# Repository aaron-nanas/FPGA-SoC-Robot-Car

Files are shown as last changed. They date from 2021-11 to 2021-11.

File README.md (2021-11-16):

# Introduction
This repository includes the Vivado project files of robot car project for my ECE 520 class (System on Chip Design). It makes use of Vivado's IP Integrator feature.

**Note:**
- The C code can be viewed in `Robot_Control_main.c`.
- The files used for 3D printing the structure can be found in the `3D_Models_Print_Files` directory.
- For additional details, check out `ece520_final_project_report.pdf` for a detailed report of this project.

[Click here to watch a short video demonstration.](https://youtu.be/ALcJU5NfLdA)

# Description
Implemented using a Zedboard and written in C, this project involves Vivado's IP Integrator feature and allows interaction with the board's processor. Four DC motors with encoders are used, while a servo controls the attached gripper. For motion control, two Pmod Joysticks ([JSTK2](https://digilent.com/reference/pmod/pmodjstk2/start)) set the directions for the motors.

Moreover, in this design, interrupts are enabled for the push buttons in order to configure the speed of the DC motors.

The structure is mostly 3D printed using the [Original Prusa MINI+](https://shop.prusa3d.com/en/3d-printers/994-original-prusa-mini.html) Printer with PLA filament.

# Block Diagram

Top-Level Hierarchy:

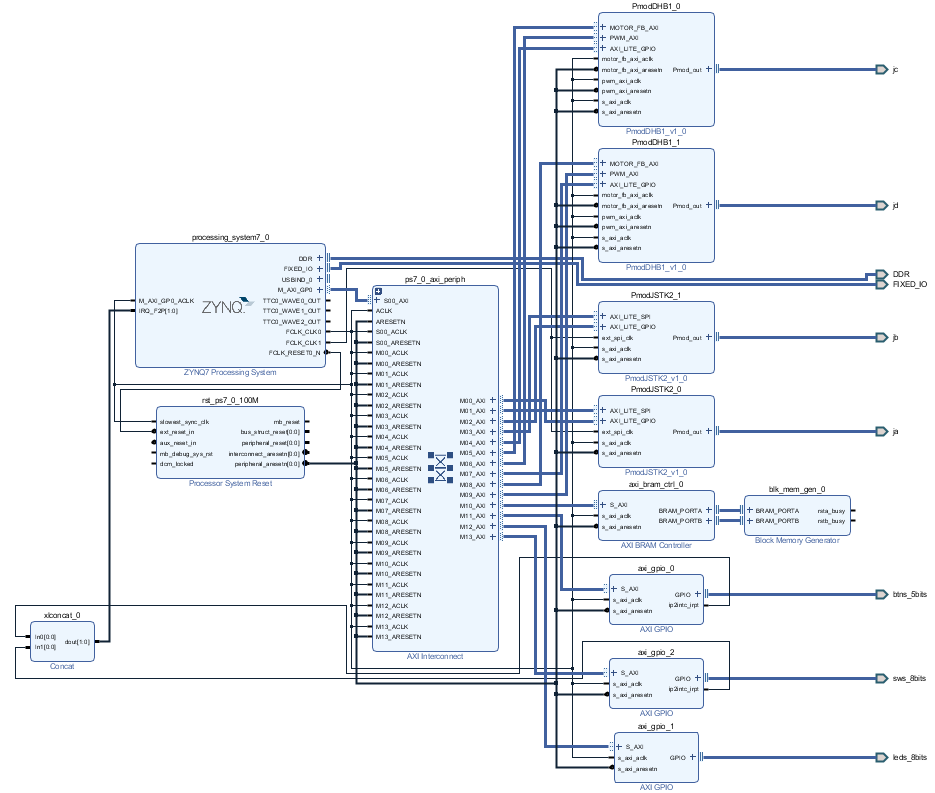
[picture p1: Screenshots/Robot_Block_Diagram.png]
Block Diagram


# Zedbot

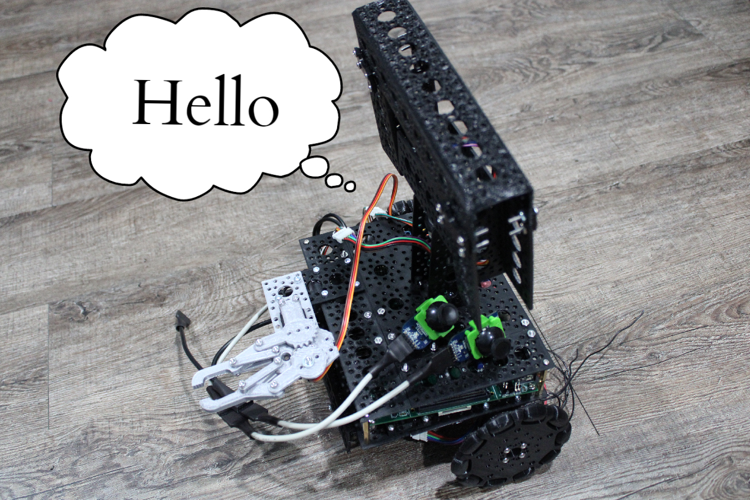
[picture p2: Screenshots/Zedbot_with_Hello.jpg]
Zedbot Image 1


Zedbot Image 2

## Underside of the Zedbot

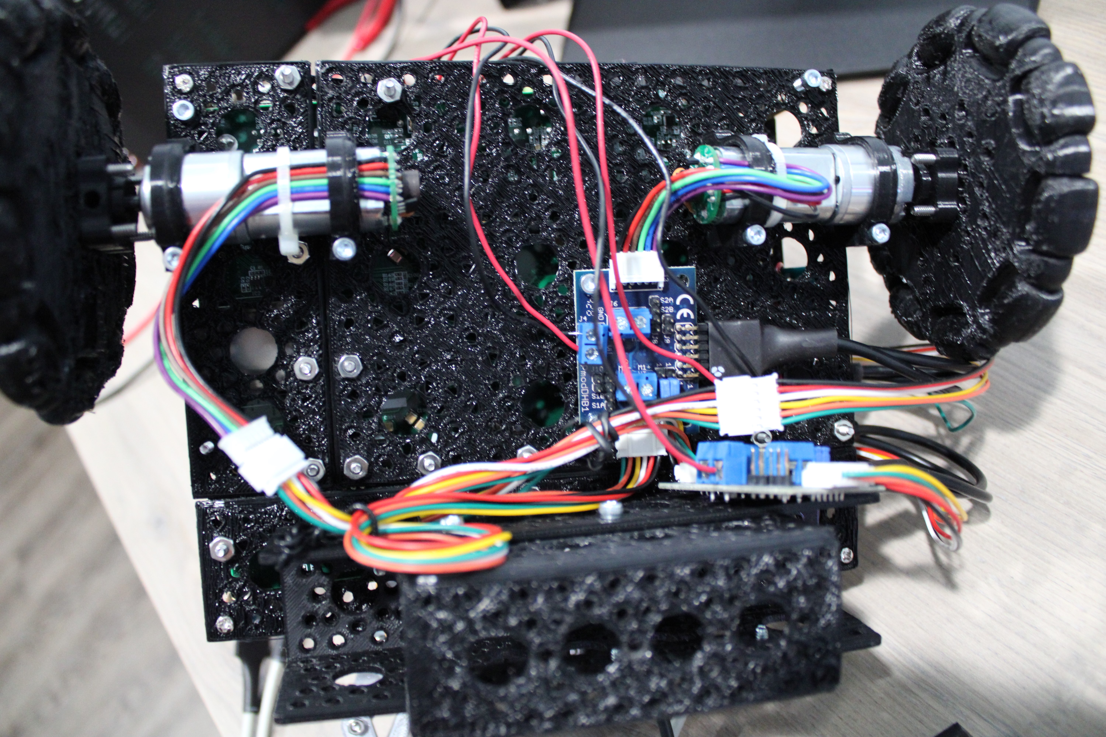
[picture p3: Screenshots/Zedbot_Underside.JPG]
Zedbot Image 3


# Video Demonstration Links

Short Video Demonstration:

[Video Demonstration 1](https://youtu.be/ALcJU5NfLdA)

More about the code:

[Video Demonstration 2](https://youtu.be/0ILeQoVi7fs)

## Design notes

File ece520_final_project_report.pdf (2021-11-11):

# ECE 520

# System on Chip Design

# Final Project Report

# FPGA/SoC Robot Car: Zedbot

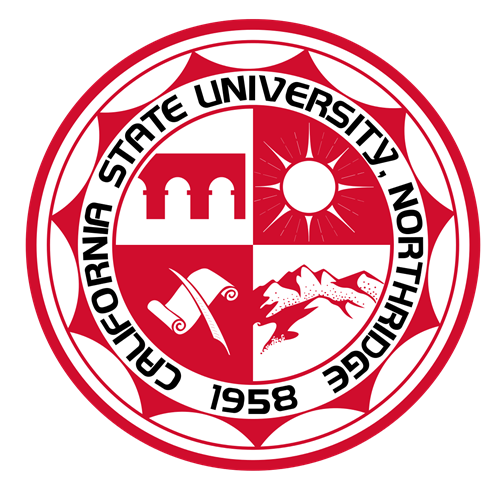
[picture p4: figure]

## Performed By: Aaron Joseph Nanas

## May 17, 2021

## Spring 2021

## Table of Contents

Section | Pg.
Overview | 2
Components Used | 2
Interfacing MIO Pmod | 2
Results | 3-10
References | 11
Appendix | 12-21

## Overview:

This project aims to construct a simple robot car with a pan-and-tilt arm (2-axis) and a gripper using the SoC design flow. The project is implemented using a Zedboard and Digilent Pmods. Vivado 2019.2 with Vitis was used. The design goals are as follows: - Using ServoCity’s open-source 3D models, design a 3D model that can properly house four DC motors with encoders and one servo motor - The design will contain an upper-level platform for a simple 2-DoF (Degrees of Freedom) arm that will eventually hold a camera - The structure must be mostly 3D printed - Two joysticks will control the motion for the DC motors and the servo motor

### The overall structure is mostly 3D printed with Prusament PLA filament, excluding standoffs, nuts, and bolts. The 3D design was created in FreeCAD using ServoCity’s 3D models. Moreover, the gripper model was obtained from an open-source Thingiverse

project.

## Components Used:

The Digilent Pmods used are the following: - Two Pmod JSTK for motion control - Two Pmod DHB1 to drive four DC motors with encoders. These motors control the wheels and the 2-DoF arm - One Pmod CON3 to interface the servo - The Pmod CON3 is connected to the Zedboard’s MIO Pmod (JE) - This Pmod also allows the servo to be separately powered ■ An external power supply (6V) was used to power both the DC motors and the servo motor

## Interfacing MIO Pmod:

### The four Pmod ports (JA, JB, JC, JD) of the Zedboard were already used by the two

Pmod JSTK2 and the two Pmod DHB1. In order to interface the servo motor, the MIO Pmod, specifically the JE1 port, was used to create a simple PWM output. This can easily be done

by writing directly to the pins and using the usleep() function to generate both the frequency required by the servo motor and the duty cycle needed to make a rotation. The driver functions needed for the PS GPIO can be found in the “XGpiops.h” header file. The function that implements a simple PWM output is shown in Figure 2. Moreover, the pins can

be found in the Zedboard’s Hardware User Guide, as shown in Figure 3.

### The rest of the code can be found in the Appendix section of the report, which will

show the functions to drive the car and the push button ISR.

## Results:


### Fig. 1: Zedbot Block Diagram

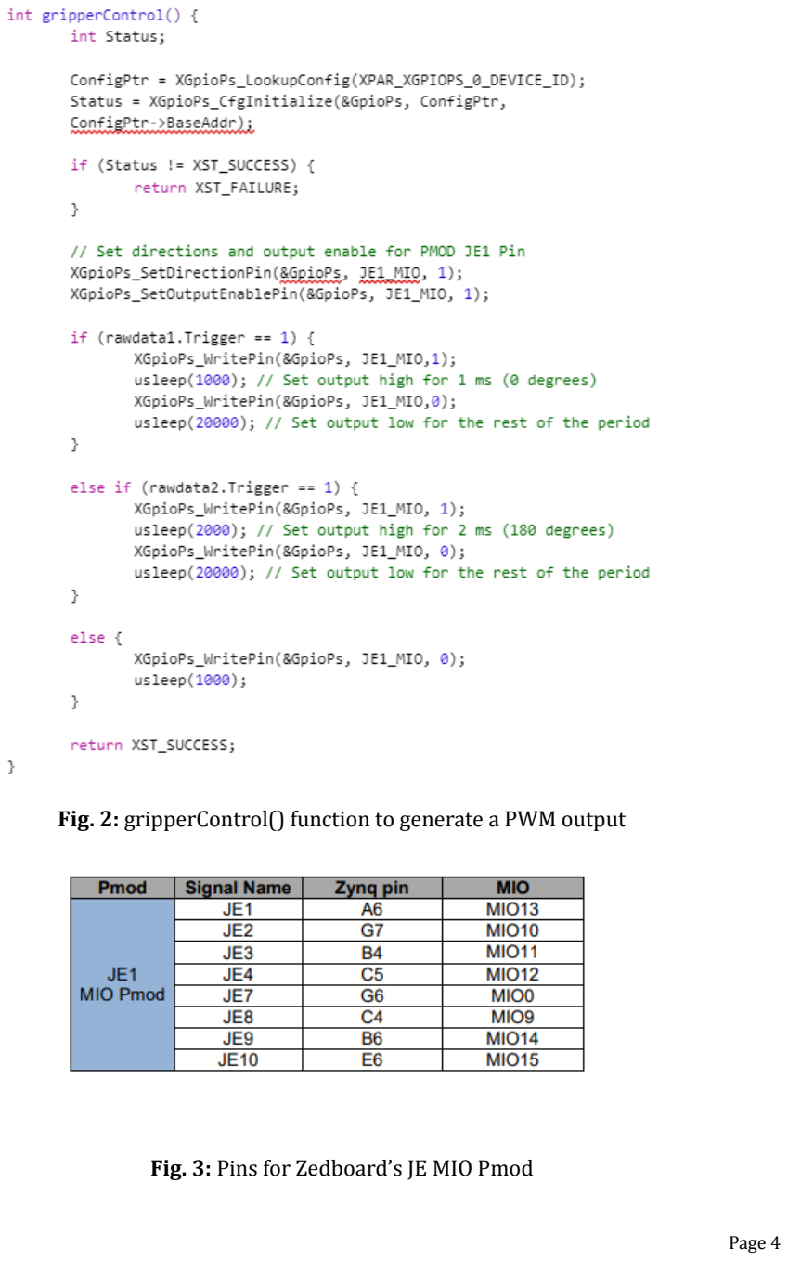
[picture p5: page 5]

### Fig. 2: gripperControl() function to generate a PWM output

### Fig. 3: Pins for Zedboard’s JE MIO Pmod

### Figure 4 presents the 3D two-axis arm model that I designed using ServoCity’s

open-source files.

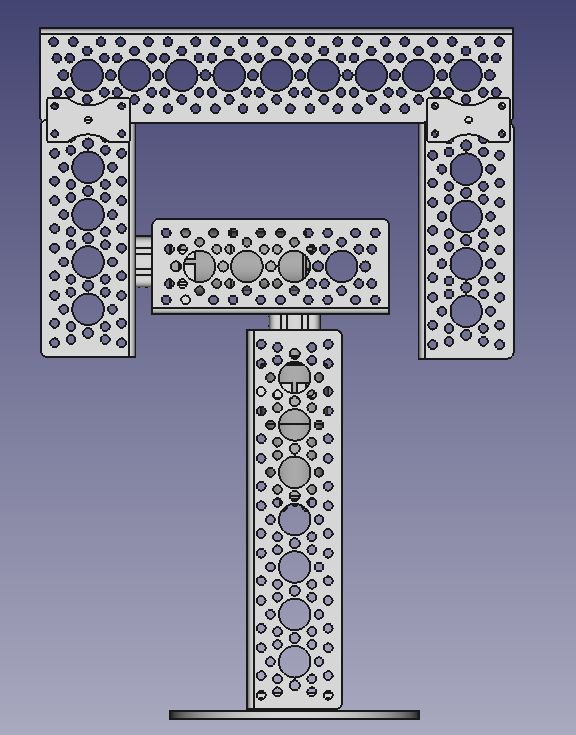
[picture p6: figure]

### Fig. 4: Simple pan-and-tilt arm

Since this is the project’s initial design, the Zedbot can only perform simple tasks: - It can drive forward and backward. It currently does not have steering capability - It can fully rotate the base of the arm, or move it up or down - The idea is that in the future, a camera will be implemented with the Zedboard, providing motion control to a camera and control its positioning - It can grab something close to it with a gripper - Motor speed can be configured with the push button interrupt service routine (ISR)

The following lists the functions used in the main program, with short descriptions for each

function: - void initializePMOD() - This initializes the Pmod JSTK2 and the Pmod DHB1 - void runRobotArm() - This initializes the default speed of the motors - It makes a call to the push button ISR, which can configure the motor speeds - It calls the other functions to drive the robot. It also continuously reads the X and Y values of the two joysticks, and then it initializes the RGB LED located on the joystick - void rotateArm() - This will either tilt the two-axis arm forward or backward, depending on the first joystick’s X and Y values - void rotateBase()

- This will rotate the base of the arm either counter-clockwise or clockwise,

depending on the first joystick’s X and Y values - void driveForward() - This will allow the car to move forward until the specified amount of positive edges is reached (via the feedbackCounter function) depending on the second joystick’s Y values - void driveBackward() - This will allow the car to move backward until the specified amount of positive edges is reached (via the feedbackCounter function) depending on the second joystick’s X values - int gripperControl() - This controls the gripper using the Pmod MIO JE1 port. It uses the usleep() function to generate the frequency and the duty cycle. It directly writes to the PS GPIO using the XGpiops.h header file

- void feedbackCounter_1() and void feedbackCounter_2() - These functions enable the Pmod DHB1 and it will calculate the amount of positive edges when the motor runs. Note that the DC motor has encoders - void BTN_Intr_Handler - The push button interrupt service routine that will configure the motor speeds. Pressing the center button will display the current speeds - int InterruptSystemSetup - Enables the interrupt system for the push buttons - int IntcInitFunction() - This initializes the interrupt controller, and it will enable the GPIO interrupts

### The fully assembled car is shown in the following figure:

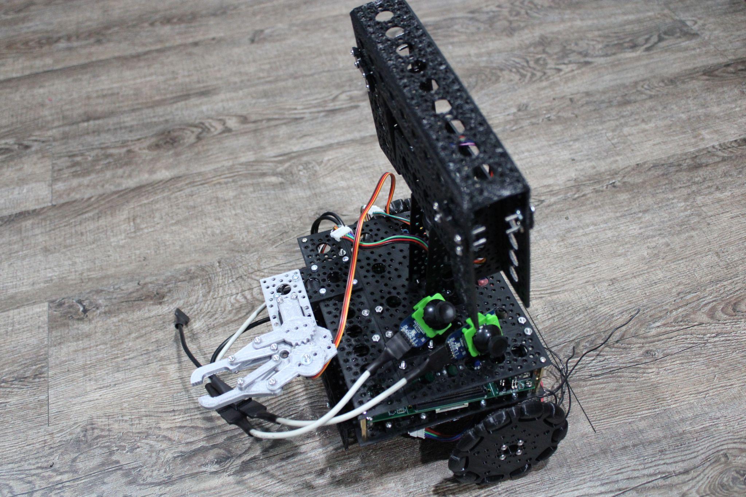
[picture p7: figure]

### Fig. 5: Fully Assembled Car

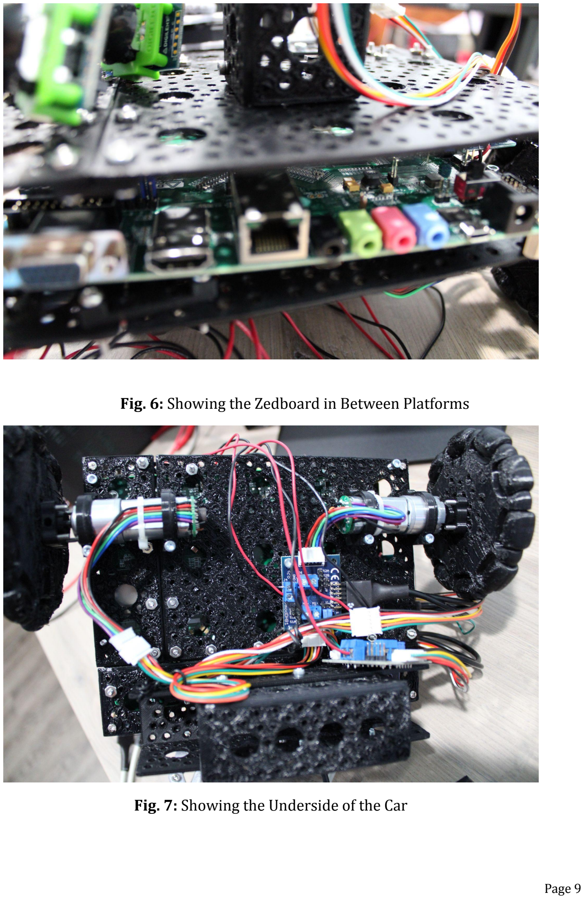
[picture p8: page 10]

### Fig. 6: Showing the Zedboard in Between Platforms

### Fig. 7: Showing the Underside of the Car

### To verify the PWM output, I used an oscilloscope to test if there are any signals coming out of the MIO Pmod of the Zedboard. Figure 8 shows three PWM outputs from the

JE port.

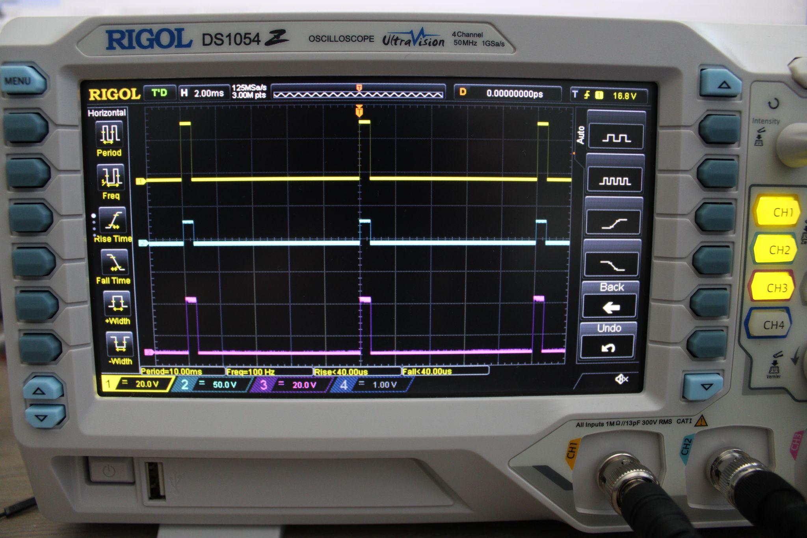
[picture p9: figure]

### Fig. 8: Checking PWM with Oscilloscope

## Video Demonstration Links:

### - Zedbot Short Demonstration: https://youtu.be/0ILeQoVi7fs - Zedbot Second Short Demonstration: https://youtu.be/ALcJU5NfLdA

## References

ServoCity STEP File Library: https://www.servocity.com/step-files/ 3D Model for Arm Claw Gripper: https://www.thingiverse.com/thing:969447 Interfacing Digilent Pmod IPs: https://reference.digilentinc.com/learn/programmable-logic/tutorials/pmod-ips/start Zedboard Reference Manual and Hardware User Guide: https://reference.digilentinc.com/programmable-logic/zedboard/reference-manual

## Appendix:

### Robot Control Main Source C Code:

/* Aaron Joseph Nanas
* ECE 520
* Professor Mirzaei
* Final Project: Robot Car with Arm
*
* Note: Connections are as follows:
* -- First Pmod DHB1: Horizontal and Vertical Axes Motors
* -- Second Pmod DHB1: Wheels
* -- First Pmod JSTK2: Controls the Horizontal and Vertical Axes Motors * -- Second Pmod JSTK2: Controls the wheels
* -- Servo (Pmod MIO JE1): Controls the gripper
*/

// Include Files
#include <stdio.h>

#include <xparameters.h>

#include <xgpiops.h>

#include <xgpio.h>

#include <xscugic.h>

#include <xil_exception.h> #include <xstatus.h>

#include <PmodJSTK2.h>

#include <MotorFeedback.h> #include <PmodDHB1.h>

#include <PWM.h>

#include <sleep.h>

#include <xil_cache.h>

#include <xil_printf.h>

// Base addresses for button ISR
#define INTC_DEVICE_ID | XPAR_PS7_SCUGIC_0_DEVICE_ID

#define BTNS_DEVICE_ID | XPAR_AXI_GPIO_0_DEVICE_ID

#define INTC_GPIO_INTERRUPT_ID

XPAR_FABRIC_AXI_GPIO_0_IP2INTC_IRPT_INTR
#define BTN_INT | XGPIO_IR_CH1_MASK

// Base addresses for first Pmod DHB1
#define GPIO_BASEADDR_1 | XPAR_PMODDHB1_0_AXI_LITE_GPIO_BASEADDR

#define PWM_BASEADDR_1 | XPAR_PMODDHB1_0_PWM_AXI_BASEADDR

#define MOTOR_FB_BASEADDR_1 XPAR_PMODDHB1_0_MOTOR_FB_AXI_BASEADDR

// Base addresses for second Pmod DHB1
#define GPIO_BASEADDR_2 | XPAR_PMODDHB1_1_AXI_LITE_GPIO_BASEADDR

#define PWM_BASEADDR_2 | XPAR_PMODDHB1_1_PWM_AXI_BASEADDR

#define MOTOR_FB_BASEADDR_2 XPAR_PMODDHB1_1_MOTOR_FB_AXI_BASEADDR

#define CLK_FREQ 100000000 // FCLK0 frequency not found in xparameters.h #define CPU_CLOCK_FREQ_HZ (XPAR_PS7_CORTEXA9_0_CPU_CLK_FREQ_HZ)

#define JE1_MIO 13

// Variables for first Pmod DHB1
#define PWM_PER_1 | 2

#define SENSOR_EDGES_PER_REV_1 | 4

#define GEARBOX_RATIO_1 | 53

// Variables for second Pmod DHB1
#define PWM_PER_2 | 2

#define SENSOR_EDGES_PER_REV_2 | 4

#define GEARBOX_RATIO_2 | 53

// Function Prototypes: Motor Control void initializePMOD();
void runRobotArm();
void rotateArm();
void rotateBase();
void driveForward();
void driveBackward();
int gripperControl();
void feedbackCounter_1(int16_t sensor_edges_1); void feedbackCounter_2(int16_t sensor_edges_2);

// Function Prototypes: Push Button ISR
int initializeButtons();
static void BTN_Intr_Handler(void *baseaddr_p);
static int InterruptSystemSetup(XScuGic *XScuGicInstancePtr); static int IntcInitFunction(u16 DeviceId, XGpio *GpioInstancePtr);

// Global Variables and Structs Initialization
PmodJSTK2 joystick1;
PmodJSTK2 joystick2;
PmodDHB1 pmodDHB1_1;
PmodDHB1 pmodDHB1_2;
MotorFeedback motorFeedback1; MotorFeedback motorFeedback2; JSTK2_Position position1;
JSTK2_DataPacket rawdata1; JSTK2_Position position2;

JSTK2_DataPacket rawdata2; XGpioPs GpioPs;
XGpioPs_Config *ConfigPtr; XGpio BTNInst;
XScuGic INTCInst;

static int btn_value;
static int DHB1_1_MOTOR_SPEED; static int DHB1_2_MOTOR_SPEED;

// Calling Functions to Main int main() {

while(1) {
initializePMOD();
runRobotArm();
}

return 0;
}

void initializePMOD() {
DHB1_begin(&pmodDHB1_1, GPIO_BASEADDR_1, PWM_BASEADDR_1, CLK_FREQ, PWM_PER_1); MotorFeedback_init(
&motorFeedback1,
MOTOR_FB_BASEADDR_1,
CLK_FREQ,
SENSOR_EDGES_PER_REV_1,
GEARBOX_RATIO_1
);
DHB1_motorDisable(&pmodDHB1_1);

DHB1_begin(&pmodDHB1_2, GPIO_BASEADDR_2, PWM_BASEADDR_2, CLK_FREQ, PWM_PER_2); MotorFeedback_init(
&motorFeedback2,
MOTOR_FB_BASEADDR_2,
CLK_FREQ,
SENSOR_EDGES_PER_REV_2,
GEARBOX_RATIO_2
);
DHB1_motorDisable(&pmodDHB1_2);

// Initialize the Pmod Joystick device JSTK2_begin(
&joystick1,
XPAR_PMODJSTK2_0_AXI_LITE_SPI_BASEADDR, XPAR_PMODJSTK2_0_AXI_LITE_GPIO_BASEADDR

);

// Set inversion register to invert only the Y axis JSTK2_setInversion(&joystick1, 0, 1);

// Initialize Joystick 2 device
JSTK2_begin(
&joystick2,
XPAR_PMODJSTK2_1_AXI_LITE_SPI_BASEADDR, XPAR_PMODJSTK2_1_AXI_LITE_GPIO_BASEADDR
);

// Set inversion register to invert only the Y axis JSTK2_setInversion(&joystick2, 0, 1);
}

int initializeButtons() {
int status;

status = XGpio_Initialize(&BTNInst, BTNS_DEVICE_ID);

if(status != XST_SUCCESS) return XST_FAILURE;

XGpio_SetDataDirection(&BTNInst, 1, 0xFF);

// Initialize interrupt controller
status = IntcInitFunction(INTC_DEVICE_ID, &BTNInst); if(status != XST_SUCCESS) return XST_FAILURE;

return 0;
}

void runRobotArm() {
DHB1_1_MOTOR_SPEED = 50;
DHB1_2_MOTOR_SPEED = 90;
DHB1_setMotorSpeeds(&pmodDHB1_1, DHB1_1_MOTOR_SPEED, DHB1_1_MOTOR_SPEED); DHB1_setMotorSpeeds(&pmodDHB1_2, DHB1_2_MOTOR_SPEED, DHB1_2_MOTOR_SPEED);

initializeButtons();
MotorFeedback_clearPosCounter(&motorFeedback1); MotorFeedback_clearPosCounter(&motorFeedback2); // Get X and Y values of the Joystick position1 = JSTK2_getPosition(&joystick1); position2 = JSTK2_getPosition(&joystick2);
// Get Joystick button data
rawdata1 = JSTK2_getDataPacket(&joystick1); rawdata2 = JSTK2_getDataPacket(&joystick2);

//xil_printf(
// | "%s%s%s%s\r\n",
// | (rawdata1.Jstk != 0) ? "\tJoystick 1 pressed" : "",
// | (rawdata1.Trigger != 0) ? "\tTrigger 1 pressed" : "",
// | (rawdata2.Jstk != 0) ? "\tJoystick 2 pressed" : "",
// | (rawdata2.Trigger != 0) ? "\tTrigger 2 pressed" : ""
// | );
//usleep(50000);

// Initialize the Joystick RGB LEDs
if ((rawdata1.Jstk != 0 || rawdata1.Trigger != 0) && (rawdata2.Jstk == 0 || rawdata2.Trigger == 0)) {
JSTK2_setLedRGB(&joystick1, 0, 255, 0);
}
else if ((rawdata2.Jstk != 0 || rawdata2.Trigger != 0) && (rawdata1.Jstk == 0 || rawdata1.Trigger == 0)) {
| JSTK2_setLedRGB(&joystick2, 0, 255, 0);
}
else {
| JSTK2_setLedRGB(&joystick1, position1.XData, 0, position1.YData);
| JSTK2_setLedRGB(&joystick2, position2.XData, 0, position2.YData);
}
driveForward();
driveBackward();
rotateArm();
rotateBase();
gripperControl();
}

void rotateArm() {
DHB1_setMotorSpeeds(&pmodDHB1_1, 0, 50);
if ((position1.XData == 128) && (position1.YData >= 150)) { // Checks for when the first joystick's direction is up
| DHB1_motorDisable(&pmodDHB1_1);
| usleep(6);
| DHB1_setDirs(&pmodDHB1_1, 0, 0); // Move the arm forward
| feedbackCounter_1(5);
}

else if ((position1.XData == 128) && (position1.YData <= 100)) { // Checks for when the first joystick's direction is down
| DHB1_motorDisable(&pmodDHB1_1);
| usleep(6);
| DHB1_setDirs(&pmodDHB1_1, 1, 1); // Move the arm backward
| feedbackCounter_1(5);

}
}

void rotateBase() {
DHB1_setMotorSpeeds(&pmodDHB1_1, 50, 0);
if ((position1.XData <= 100) && (position1.YData == 128)) { // Checks for when the first joystick's direction is left
DHB1_motorDisable(&pmodDHB1_1);
usleep(6);
DHB1_setDirs(&pmodDHB1_1, 1, 1); // Rotate the base counter-clockwise feedbackCounter_1(5);
}

else if ((position1.XData >= 150) && (position1.YData == 128)) { // Checks for when the first joystick's direction is right DHB1_motorDisable(&pmodDHB1_1);
usleep(6);
DHB1_setDirs(&pmodDHB1_1, 0, 0); // Rotate the base clockwise feedbackCounter_1(5);
}
}

void driveForward() {
if ((position2.XData == 128) && (position2.YData >= 129)) { // Checks for when the second joystick's direction is up DHB1_motorDisable(&pmodDHB1_2); // Disable the PWM before the motors change direction
usleep(6); | // Adding a short delay to prevent
short circuit
DHB1_setDirs(&pmodDHB1_2, 1, 1); // Set direction forward feedbackCounter_2(240); // Motor runs until the specified amount of positive edges is reached
}
}

void driveBackward() {
if ((position2.XData == 128) && (position2.YData <= 127)) { // Checks for when the second joystick's direction is down DHB1_motorDisable(&pmodDHB1_2); // Disable the PWM before the motors change direction
usleep(6); | // Adding a short delay to prevent
short circuit
DHB1_setDirs(&pmodDHB1_2, 0, 0); // Set direction backward feedbackCounter_2(240); // Motor runs until the specified amount of positive edges is reached
}
}

// Function to drive the servo using the Pmod MIO JE1 port
// Uses usleep function to generate the frequency and duty cycle int gripperControl() {
int Status;

ConfigPtr = XGpioPs_LookupConfig(XPAR_XGPIOPS_0_DEVICE_ID); Status = XGpioPs_CfgInitialize(&GpioPs, ConfigPtr, ConfigPtr->BaseAddr);

if (Status != XST_SUCCESS) {
return XST_FAILURE;
}

// Set directions and output enable for PMOD JE1 Pin XGpioPs_SetDirectionPin(&GpioPs, JE1_MIO, 1); XGpioPs_SetOutputEnablePin(&GpioPs, JE1_MIO, 1);

if (rawdata1.Trigger == 1) {
XGpioPs_WritePin(&GpioPs, JE1_MIO,1);
usleep(1000); // Set output high for 1 ms (0 degrees) XGpioPs_WritePin(&GpioPs, JE1_MIO,0);
usleep(20000); // Set output low for the rest of the period }

else if (rawdata2.Trigger == 1) {
XGpioPs_WritePin(&GpioPs, JE1_MIO, 1);
usleep(2000); // Set output high for 2 ms (180 degrees) XGpioPs_WritePin(&GpioPs, JE1_MIO, 0);
usleep(20000); // Set output low for the rest of the period }

else {
XGpioPs_WritePin(&GpioPs, JE1_MIO, 0); usleep(1000);
}

return XST_SUCCESS;
}

void feedbackCounter_1(int16_t sensor_edges_1) { DHB1_motorEnable(&pmodDHB1_1);
int16_t dist_1 = MotorFeedback_getDistanceTraveled(&motorFeedback1); while (dist_1 < sensor_edges_1) {
dist_1 = MotorFeedback_getDistanceTraveled(&motorFeedback1);
}
MotorFeedback_clearPosCounter(&motorFeedback1);

DHB1_motorDisable(&pmodDHB1_1);
}

void feedbackCounter_2(int16_t sensor_edges_2) { DHB1_motorEnable(&pmodDHB1_2);
int16_t dist_2 = MotorFeedback_getDistanceTraveled(&motorFeedback2); while (dist_2 < sensor_edges_2) {
dist_2 = MotorFeedback_getDistanceTraveled(&motorFeedback2);
}
MotorFeedback_clearPosCounter(&motorFeedback2); DHB1_motorDisable(&pmodDHB1_2);
}

void BTN_Intr_Handler(void *InstancePtr)
{
// Disable GPIO interrupts XGpio_InterruptDisable(&BTNInst, BTN_INT);
// Ignore additional button presses
if ((XGpio_InterruptGetStatus(&BTNInst) & BTN_INT) != BTN_INT) {
return;
}
btn_value = XGpio_DiscreteRead(&BTNInst, 1);

if (btn_value == 1) {
xil_printf("\nCurrent Motor Speeds: \n" "DHB1_1 Motors: %d\n"
"DHB1_2 Motors: %d\n",DHB1_1_MOTOR_SPEED, DHB1_2_MOTOR_SPEED );
}

else if (btn_value == 4) {
xil_printf("\nLeft button (BTNL) was pressed. Decreasing DHB1_1 Motor Speed.\n");
DHB1_1_MOTOR_SPEED = DHB1_1_MOTOR_SPEED - 5;
xil_printf("\nCurrent Speed of DHB1_1 Motors (Arm/Base): %d\n", DHB1_1_MOTOR_SPEED);
}

else if (btn_value == 8) {
xil_printf("\nRight button (BTNR) was pressed. Increasing DHB1_1 Motor Speed.\n");
DHB1_1_MOTOR_SPEED = DHB1_1_MOTOR_SPEED + 5;
xil_printf("\nCurrent Speed of DHB1_1 Motors (Arm/Base): %d\n", DHB1_1_MOTOR_SPEED);
}

else if (btn_value == 16) {
xil_printf("\nUp button (BTNU) was pressed. Increasing DHB1_2 Motor Speed.\n");
DHB1_2_MOTOR_SPEED = DHB1_2_MOTOR_SPEED + 5;
xil_printf("\nCurrent Speed of DHB1_2 Motors (Wheels): %d\n", DHB1_2_MOTOR_SPEED);
}

else if (btn_value == 2) {
xil_printf("\nDown button (BTND) was pressed. Decreasing DHB1_2 Motor Speed.\n");
DHB1_2_MOTOR_SPEED = DHB1_2_MOTOR_SPEED - 5;
xil_printf("\nCurrent Speed of DHB1_2 Motors (Wheels): %d\n", DHB1_2_MOTOR_SPEED);
}

(void)XGpio_InterruptClear(&BTNInst, BTN_INT); // Enable GPIO interrupts
XGpio_InterruptEnable(&BTNInst, BTN_INT);
}

int InterruptSystemSetup(XScuGic *XScuGicInstancePtr) {
// Enable interrupt
XGpio_InterruptEnable(&BTNInst, BTN_INT); XGpio_InterruptGlobalEnable(&BTNInst); Xil_ExceptionRegisterHandler(XIL_EXCEPTION_ID_INT,

(Xil_ExceptionHandler)XScuGic_InterruptHandler, XScuGicInstancePtr);
Xil_ExceptionEnable();
return XST_SUCCESS;
}
int IntcInitFunction(u16 DeviceId, XGpio *GpioInstancePtr) {
XScuGic_Config *IntcConfig;
int status;

// Interrupt controller initialization
IntcConfig = XScuGic_LookupConfig(DeviceId);
status = XScuGic_CfgInitialize(&INTCInst, IntcConfig, IntcConfig->CpuBaseAddress);

if(status != XST_SUCCESS)
return XST_FAILURE;

// Call to interrupt setup status = InterruptSystemSetup(&INTCInst); if(status != XST_SUCCESS)
return XST_FAILURE;

// Connect GPIO interrupt to handler status = XScuGic_Connect(&INTCInst, INTC_GPIO_INTERRUPT_ID,
(Xil_ExceptionHandler)BTN_Intr_Handler, (void *)GpioInstancePtr);

if(status != XST_SUCCESS)
return XST_FAILURE;

// Enable GPIO interrupts interrupt XGpio_InterruptEnable(GpioInstancePtr, 1); XGpio_InterruptGlobalEnable(GpioInstancePtr);

// Enable GPIO and timer interrupts in the controller XScuGic_Enable(&INTCInst, INTC_GPIO_INTERRUPT_ID);

return XST_SUCCESS;
}

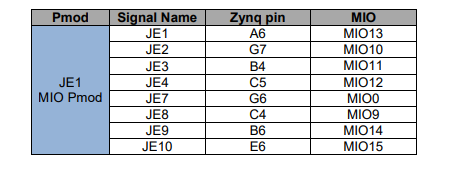
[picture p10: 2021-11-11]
Screenshots/zedboard_mio.png

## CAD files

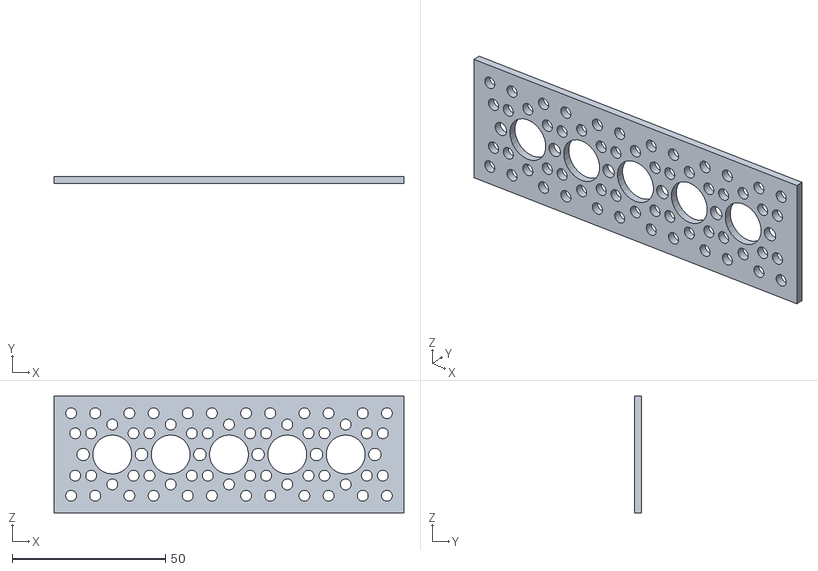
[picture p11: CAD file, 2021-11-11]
3D_Models_Print_Files/RobotArm_V3_STL_Files/1-5in_4-50in_PatternPlate.stl
114.3 x 2.29 x 38.1

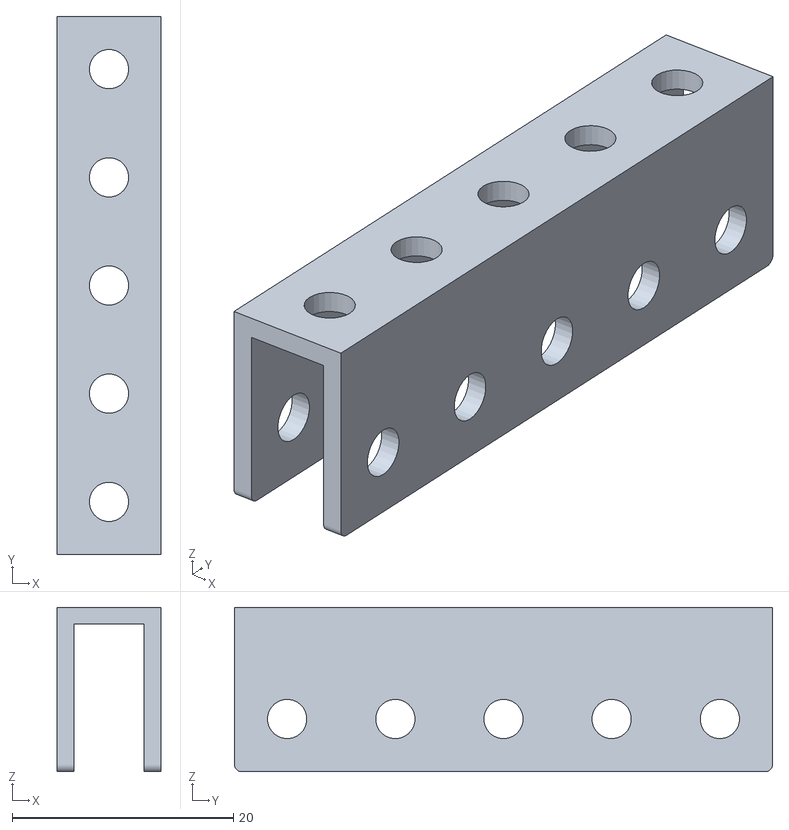
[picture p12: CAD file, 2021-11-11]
3D_Models_Print_Files/RobotArm_V3_STL_Files/1-54in_U-Beam.stl
9.40 x 48.6 x 14.9

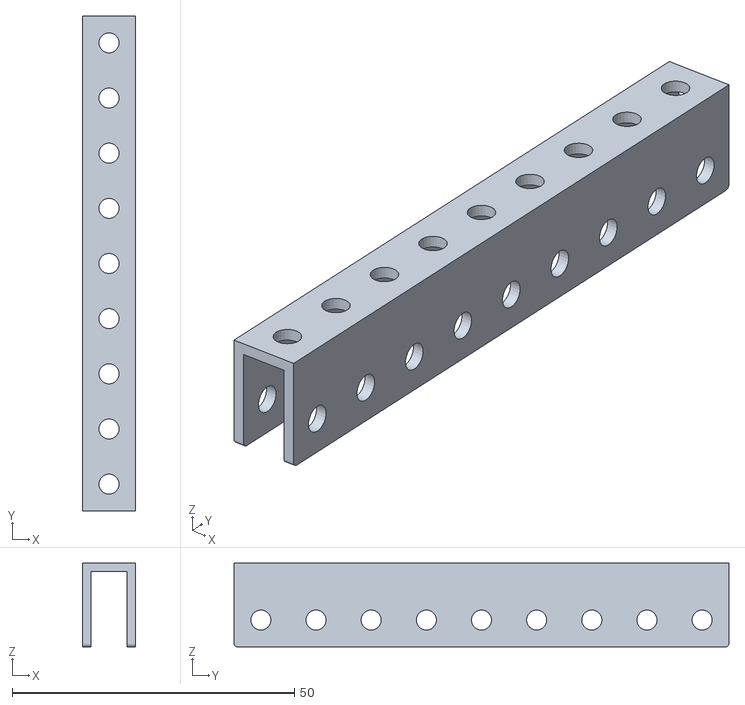
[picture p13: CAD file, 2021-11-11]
3D_Models_Print_Files/RobotArm_V3_STL_Files/3-08in_U-Beam.stl
9.40 x 87.8 x 14.9

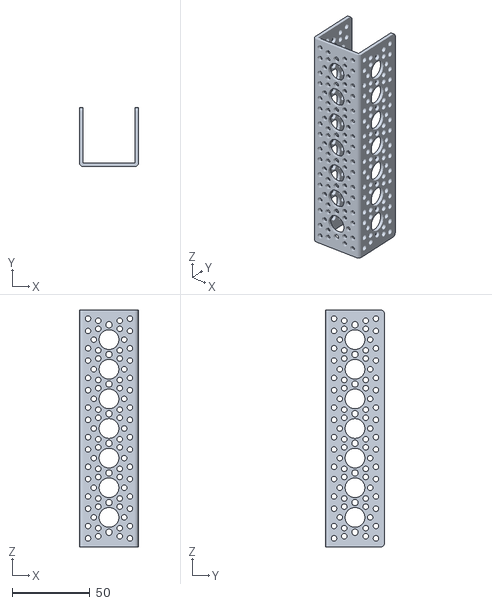
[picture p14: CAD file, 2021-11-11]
3D_Models_Print_Files/RobotArm_V3_STL_Files/6in_U-Channel.stl
38.1 x 38.1 x 152.4

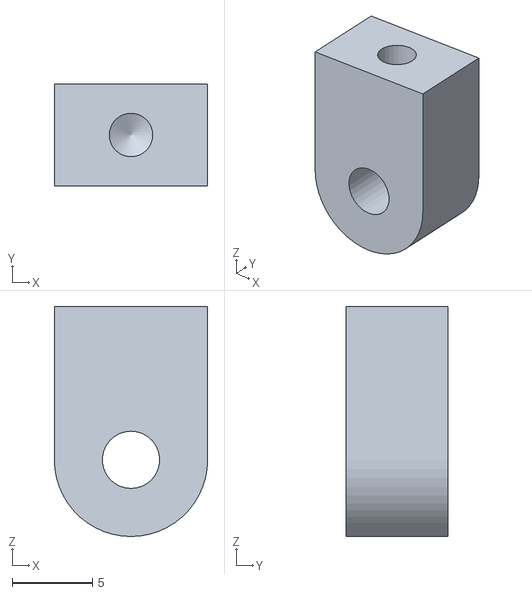
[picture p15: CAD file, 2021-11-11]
3D_Models_Print_Files/RobotArm_V3_STL_Files/Beam_Attachment_Blocks_585403.stl
9.52 x 6.35 x 14.3

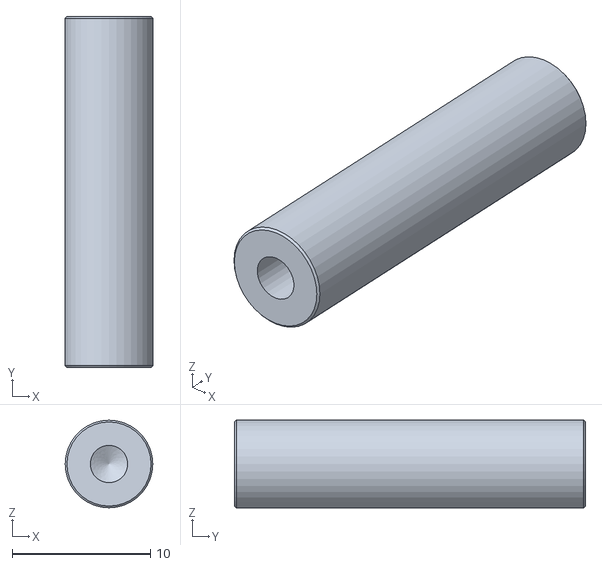
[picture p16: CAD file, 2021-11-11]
3D_Models_Print_Files/RobotArm_V3_STL_Files/1in_Standoff.stl
6.34 x 25.4 x 6.34

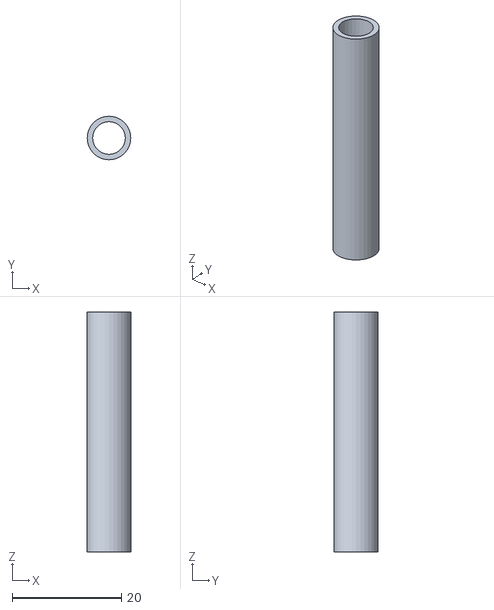
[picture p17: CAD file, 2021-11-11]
3D_Models_Print_Files/RobotArm_V3_STL_Files/4mm-22mm_Tube.stl
8.00 x 8.00 x 44.0

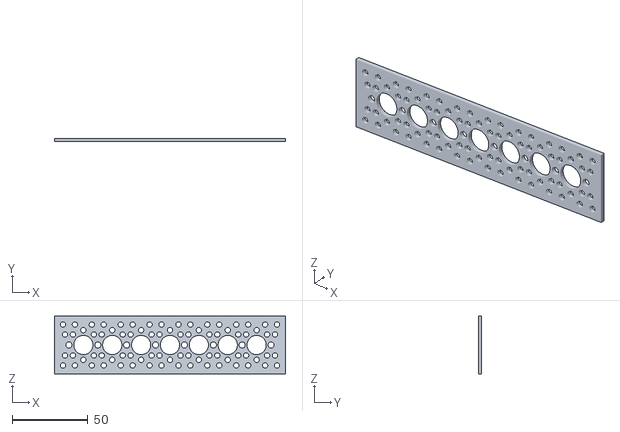
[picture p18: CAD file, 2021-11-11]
3D_Models_Print_Files/RobotArm_V3_STL_Files/1-5in_6in_PatternPlate.stl
152.4 x 2.29 x 38.1

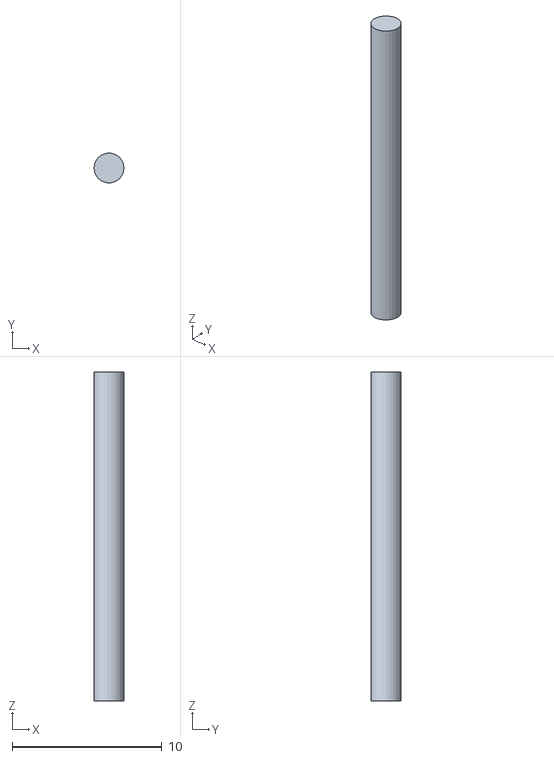
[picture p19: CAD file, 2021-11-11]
3D_Models_Print_Files/RobotArm_V3_STL_Files/TubeTest_v2.stl
2.00 x 1.99 x 22.0

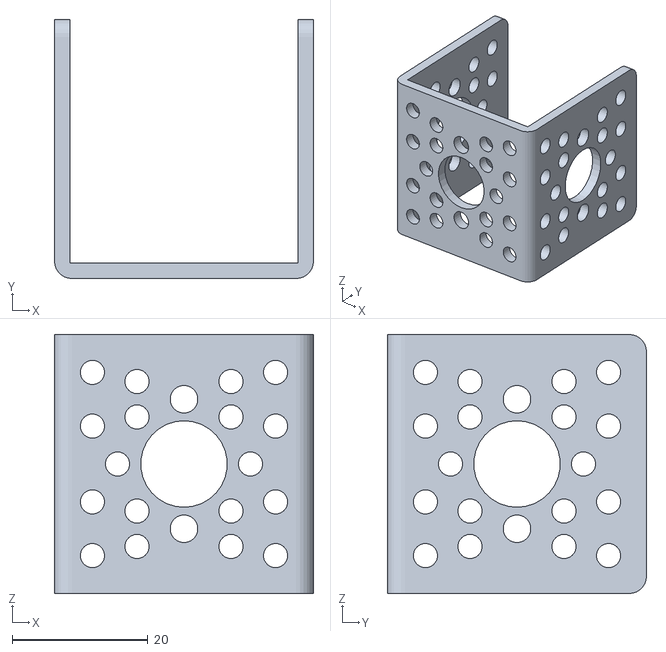
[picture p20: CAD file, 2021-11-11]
3D_Models_Print_Files/RobotArm_V3_STL_Files/1-50in_U-Channel.stl
38.1 x 38.1 x 38.1

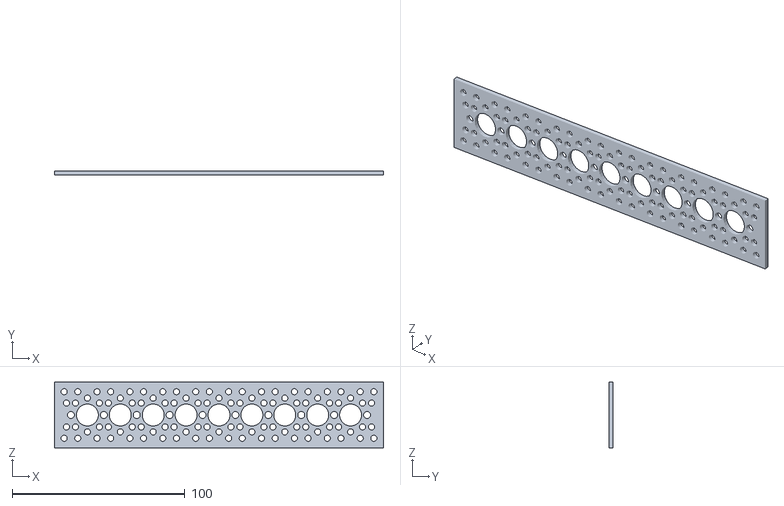
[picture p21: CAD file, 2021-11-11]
3D_Models_Print_Files/RobotArm_V3_STL_Files/1-5in_7-5in_PatternPlate.stl
190.5 x 2.29 x 38.1

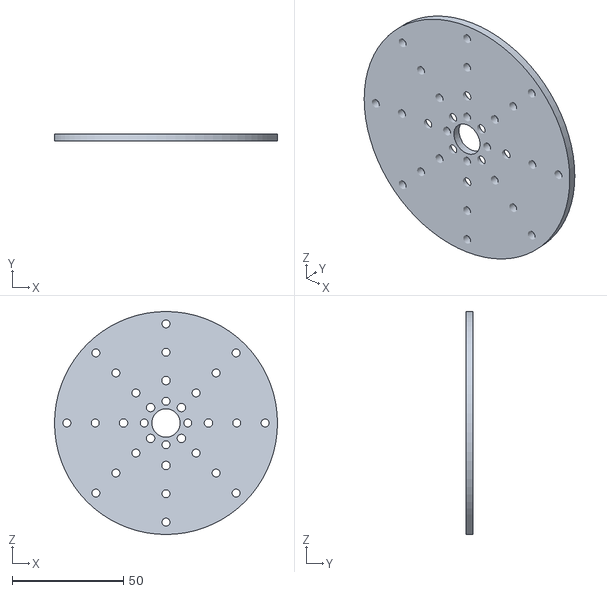
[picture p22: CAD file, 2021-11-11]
3D_Models_Print_Files/RobotArm_V3_STL_Files/Round_Baseplate.stl
100.1 x 3.17 x 100.1

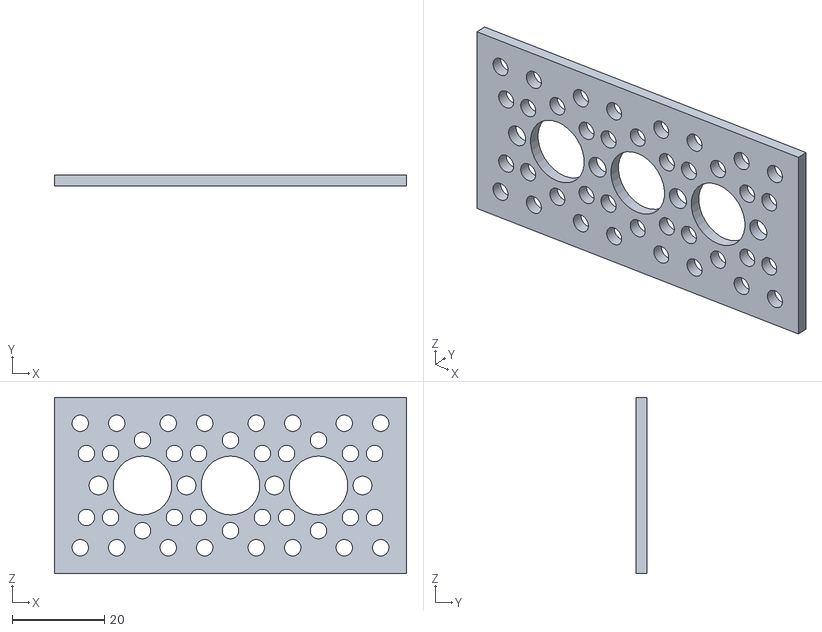
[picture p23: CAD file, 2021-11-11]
3D_Models_Print_Files/RobotArm_V3_STL_Files/1-50in_3in_PatternPlate.stl
76.2 x 2.29 x 38.1

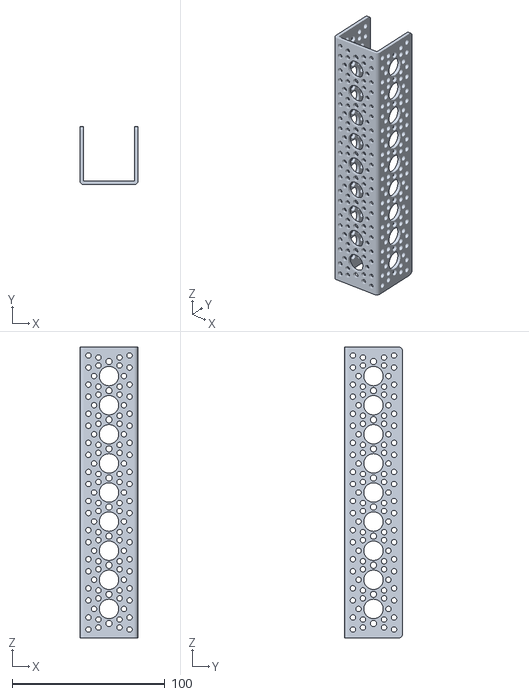
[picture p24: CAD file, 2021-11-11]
3D_Models_Print_Files/RobotArm_V3_STL_Files/7-5in_U-Channel.stl
38.1 x 38.1 x 190.5

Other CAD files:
3D_Models_Print_Files/RobotArm_V3_STL_Files/Channel_Connector_Plate_545532.stl
3D_Models_Print_Files/RobotArm_V3_STL_Files/1206-Series_Pattern_Adaptor_32-6.stl
3D_Models_Print_Files/RobotArm_V3_STL_Files/tubeTest.stl
3D_Models_Print_Files/RobotArm_V3_STL_Files/4mm-26mm_Tube.stl
3D_Models_Print_Files/RobotArm_V3_STL_Files/3-8in_RoundScrewPlate.stl
3D_Models_Print_Files/RobotArm_V3_STL_Files/4-50in_6in_Plate.stl
3D_Models_Print_Files/RobotArm_V3_STL_Files/4mm-SetScrewHub.stl
3D_Models_Print_Files/RobotArm_V3_STL_Files/4mm_Bore_SetScrew_Hub.stl
3D_Models_Print_Files/RobotArm_V3_STL_Files/SideTapped_PatternMount_545360.stl

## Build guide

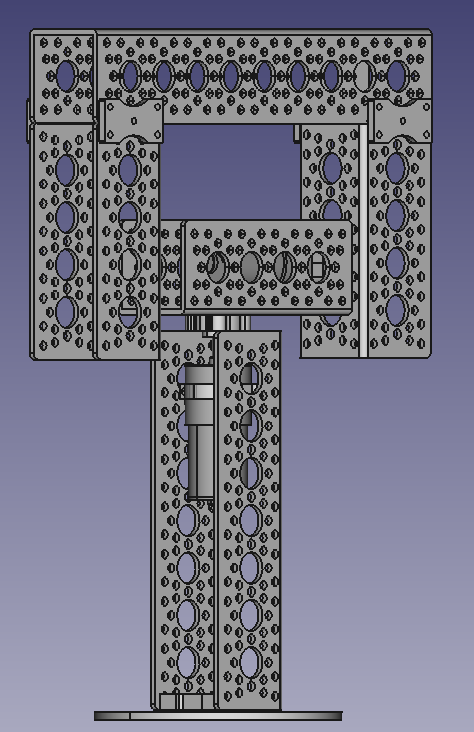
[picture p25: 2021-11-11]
3D_Models_Print_Files/2-DoF_Arm2.png

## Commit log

2021-11-11 Uploaded project files, block diagram, and Zedbot pictures
    [1-50in_3in_PatternPlate.stl, 1-50in_U-Channel.stl, 1-54in_U-Beam.stl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]
2021-11-11 Update project directory
    [1-50in_3in_PatternPlate.stl, 1-50in_U-Channel.stl, 1-54in_U-Beam.stl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]
